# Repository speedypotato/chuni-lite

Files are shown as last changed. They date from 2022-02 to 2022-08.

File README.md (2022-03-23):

# chuni-lite
Slidy air towers for an arcade chuni slider without backplate.  Bare minimum docs because I don't expect too many people to have access to chuni cab sliders without backplates.

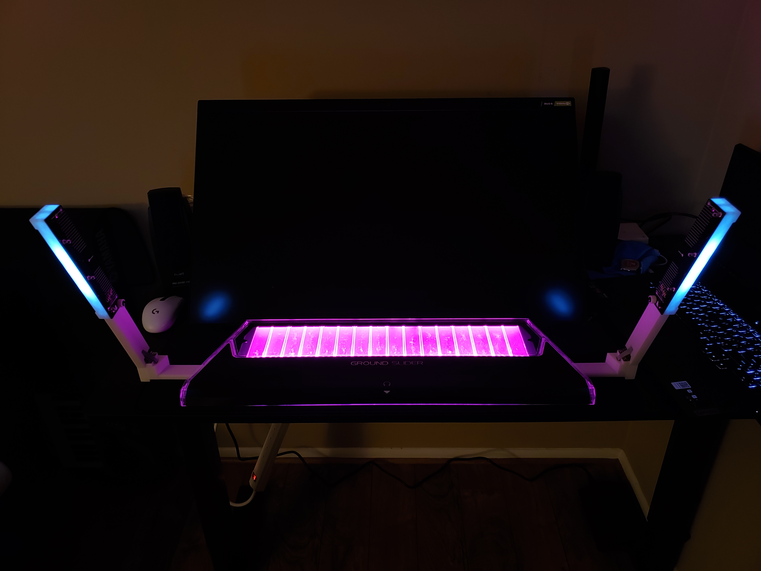
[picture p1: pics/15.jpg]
chuni lite


Current versions can be found at:
- CAD: chuni-lite\chunair-cad\airs\print\f1
- PCB: chuni-lite\chunair\chunair\chunair_v2\v2-1-2 & chuni-lite\chunair\chunair_core\v1

Note: I swapped the side the pads are on for chunair_core.  Oops.  Wires will go across the board for now, no biggie.  WS2811/WS2812B optional.

Slider needs:
- HiLetgo 2pcs DB9 Female Adapter RS232 to Terminal RS232 Serial to Terminal DB9 Connector Convert Adapter https://www.amazon.com/gp/product/B082F873KQ (technically just one)
- CQRobot 450 Pieces 2.54mm JST-XA JST Connector Kit. 2.54mm Pitch Female Pin Header, JST XA 2/3 / 4 Pin Housing JST Adapter Cable Connector Socket Male and Female, Crimp DIP Kit. https://www.amazon.com/gp/product/B085QMRHK6 (technically just a 3 & 4 pin).  3 pin needed pegs clipped.
- USB to VGA/RS-232 Male 9 PIN DB9 Serial Cable 2 FT WIN10/8.1/8/7 PERFECT VISION https://www.amazon.com/gp/product/B097Q5D64Q/ (or any other usb to serial cable)
- 12V 1A PSU minimum with matching female barrel jack that has the screw terminals https://www.amazon.com/gp/product/B091XSVV1Y/

Air towers need:
- 1x USB C Pro Micro x1
- IR LEDs https://www.amazon.com/gp/product/B01BVGIZGC/ and IR Photodiodes https://www.amazon.com/gp/product/B01BVGIZGM (chanzon ones seem pretty high quality) x6 of each(but they come in pack of 100)
- 150 ohm resistor x6
- 10k ohm resistor x6
- some ribbon wire https://www.ebay.com/itm/334199317464 100-Feet Flat Ribbon Cable Grey 50-Conductor 28 AWG Belden 2L28050 008H100
- 12x2mm magnets https://www.ebay.com/itm/391899288494 x10 (but they come in pack of 100)
- Rubber Feet https://www.mcmaster.com/8884T21 x4
- Adhesive Rubber Feet https://www.aliexpress.com/item/1005002618606773.html x4 (but they come in pack of 100)
- M3 Nuts x18
- M3x8 x4
- M4x16 https://www.mcmaster.com/91292A118 x4 (but they come in pack of 100)
- M3x15 flat head https://www.mcmaster.com/92125A103 x8 (but they come in pack of 100)
- M3x20 round head https://www.mcmaster.com/94500A266 x6 (but they come in pack of 100)
- 1 inch hinges https://www.amazon.com/gp/product/B07WJSTNC9 (MroMax 15PCS Door Hinge 1.14" x 0.71" x 0.02" Silver Tone Metal Iron Hinges Brushed Finish Suitable for Door Cabinet Jewelry Case Wooden Box) x2 (but pack of 15) - can try other hinges but holes may not align
- 3D printed parts + a mirrored set
- USB C cable
- Hot Glue & Super Glue
- Small zip ties x4

Can hand wire, or replace air_tower_top_1 3D print with chunair pcb.  chunair_core PCB also optional, but is there for ease of wiring(find a way to secure the pro micro if you don't use chunair_core)

Basic steps:
0. Wire up your slider's 12v and DB9.  Crimps recommended.  11" 4 wire recommended for 12v, 9" 3 wire for DB9.

xa 1

xa 2

xa 3

db9 and 12v

1. Print parts.  Then print a mirrored set.  Glue magnets with super glue except for the one on slider which is inserted from the outside - glue that one in with hot glue.  Pay attention to the magnetic poles!!

chunair 3d print

2. Assemble slider_rail and air_tower with hinge, flat head screws, and nuts and insert into slider (double check orientation)

hinge

3. Glue leds/pds if you are using air_tower_top_1.  Wire according to the diagram in "ac chuni/wiring.png".  If you have PCB, solder resistors and leds/pds - 10K resistors are marked, the other 3 are 150 ohm resistors.  With PCB, recommended wire length is around 30", 9 wires for RGB, 8 for no RGB.  
3a. If you want RGB, add a 3 piece WS2812B LED strip in the middle and solder it up like the picture.

led

led pcb

4. Shove unsoldered end of ribbon cable through the channel.
5. Screw air_tower_top_2 to the pcb or air_tower_top_1(depending on which you have) using rounded m3 heads while threading through air_tower.  Don't forget to put the printed bumper piece on one of the screws.

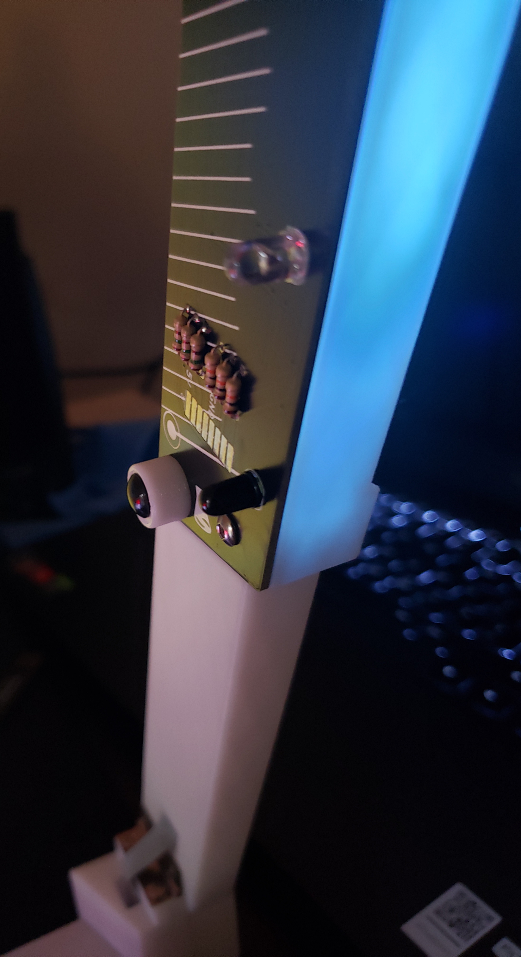
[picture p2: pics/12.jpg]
bumper


6. Solder to Pro Micro or chunair_core pcb depending on what you have.  Make sure you slide the slider_rail into the slider first before soldering.

chunair core

7. Repeat steps 2-6 for the other side.

chunair loose

chunair assembled

8. Add zip ties to core.  Use 4 m3x8 bolts and nuts to mount db9 and chunair_core to core.  Press fit 12v barrel connector and hot glue into place.

chunair core

9. Thread M4 screws through rubber foot and slider to mount to slider.

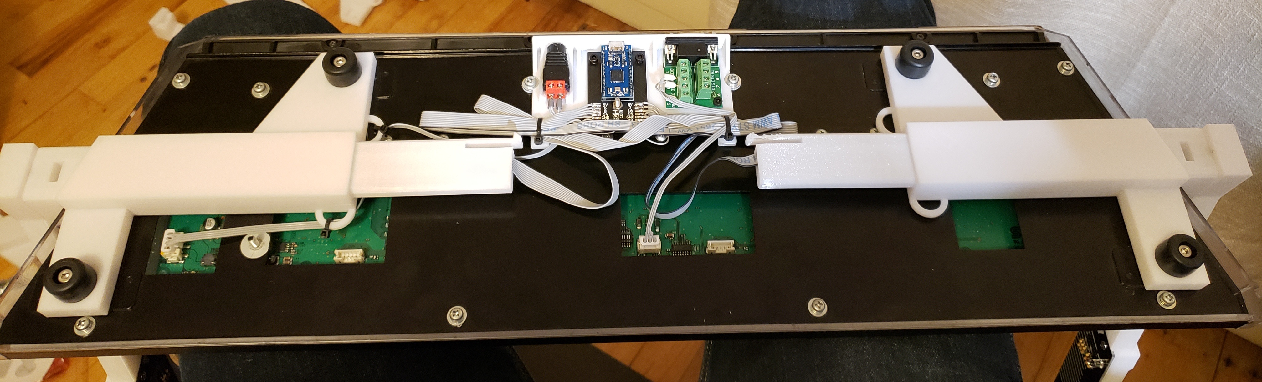
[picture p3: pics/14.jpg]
chunair core


10. Use existing M4 screws on the chunithm slider to mount core.  Zip tie down core & power cable
11. Flash firmware and test to make sure everything works.  Then add adhesive rubber feet on each bumper in addition to the bottom of the airs.

This work is licensed under a Creative Commons Attribution-NonCommercial-ShareAlike 4.0 International License.

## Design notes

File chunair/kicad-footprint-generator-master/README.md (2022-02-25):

This repository contains scripts to generate custom KiCAD footprints using python, and a framework which allows us to
create custom KiCAD footprint. A big bunch of footprints of the KiCad library was developed using this framework.

# KicadModTree

**Licence:** GNU GPLv3+

**Maintainer:** Thomas Pointhuber





**Supports:** Python 3.6+

## About

I started drawing a bunch of similar footprints for KiCAD, like connectors which are mainly one base shape, and different
amount of pins. To be able to update/improve those footprints quickly I decided to write my own footprint generator Framework,
to allow simple creation of easy as well complex shapes.

This is my second approach (the first one can be found in the git history). This solution should be able to be easy to
use, to read and also be easy to expand with custom nodes.

## Overview

This framework is mainly based on the idea of scripted CAD systems (for example OpenSCAD). This means, everything is a
node, and can be structured like a tree. In other words, you can group parts of the footprint, and translate them in any
way you want. Also cloning & co. is no problem anymore because of this concept.

To be able to create custom Nodes, I separated the system in two parts. Base nodes, which represents simple structures
and also be used by KiCAD itself, and specialized nodes which alter the behaviour of base nodes (for example positioning),
or represent a specialized usage of base nodes (for example RectLine).

When you serialize your footprint, the serialize command only has to handle base nodes, because all other nodes are based
upon the base nodes. This allows us to write specialized nodes without worrying about the FileHandlers or other core systems.
You simply create your special node, and the framework knows how to handle it seamlessly.

Please look into the **[Documentation](http://kicad-footprint-generator.readthedocs.io/en/latest/)** for further details

```
KicadModTree        - The KicadModTree framework which is used for footprint generation
docs                - Files required to generate a sphinx documentation
scripts             - scripts which are generating footprints based on this library
```

## Development

### Install development Dependencies

```sh
manage.sh update_dev_packages
```

### run tests

```sh
manage.sh tests
```

## Example Script

```python
from KicadModTree import *

footprint_name = "example_footprint"

# init kicad footprint
kicad_mod = Footprint(footprint_name)
kicad_mod.setDescription("A example footprint")
kicad_mod.setTags("example")

# set general values
kicad_mod.append(Text(type='reference', text='REF**', at=[0, -3], layer='F.SilkS'))
kicad_mod.append(Text(type='value', text=footprint_name, at=[1.5, 3], layer='F.Fab'))

# create silkscreen
kicad_mod.append(RectLine(start=[-2, -2], end=[5, 2], layer='F.SilkS'))

# create courtyard
kicad_mod.append(RectLine(start=[-2.25, -2.25], end=[5.25, 2.25], layer='F.CrtYd'))

# create pads
kicad_mod.append(Pad(number=1, type=Pad.TYPE_THT, shape=Pad.SHAPE_RECT,
                     at=[0, 0], size=[2, 2], drill=1.2, layers=Pad.LAYERS_THT))
kicad_mod.append(Pad(number=2, type=Pad.TYPE_THT, shape=Pad.SHAPE_CIRCLE,
                     at=[3, 0], size=[2, 2], drill=1.2, layers=Pad.LAYERS_THT))

# add model
kicad_mod.append(Model(filename="example.3dshapes/example_footprint.wrl",
                       at=[0, 0, 0], scale=[1, 1, 1], rotate=[0, 0, 0]))

# output kicad model
file_handler = KicadFileHandler(kicad_mod)
file_handler.writeFile('example_footprint.kicad_mod')
```
## Usage Steps

1. Navigate into the `scripts` directory, and look for the type of footprint you would like to generate. For example, if you wish to generate an SMD inductor footprint, `cd` into `scripts/Inductor_SMD`.
2. Open the \*.yaml (or \*.yml) file in a text editor. Study a few of the existing footprint definitions to get an idea of how your new footprint entry should be structured.
3. Add your new footprint by inserting your own new section in the file. An easy way to do this is by simply copying an existing footprint definition, and modifying it to suit your part. Note:  You may have to add or remove additional parameters that are not listed.
4. Save your edits and close the text editor.
5. Run the python script, passing the \*.yaml or (\*.yml) file as a parameter, e.g. `python3 Inductor_SMD.py Inductor_SMD.yml`. This will generate the \*.kicad_mod files for each footprint defined in the \*.yaml (or \*.yml).

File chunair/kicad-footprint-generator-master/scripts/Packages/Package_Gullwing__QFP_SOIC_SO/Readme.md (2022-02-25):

# IPC gullwing generator

This generator uses IPC-7351B equations and fillet definitions to derive a footprint for gullwing style packages from the dimensions of the package. (The suggested footprint is generally ignored. It is only used to define the exposed pad if necessary to fulfill thermal or EMC requirements defined in the datasheet.)
Fillet size definitions can be changed by pointing to a personalized IPC parameter file. The script generates footprints in zero orientation version A (pin 1 at top left corner).
Pads are generated using rounded rectangle pads as suggested in preliminary releases of IPC-7351C.

Examples of supported packages include: QFP, SOIC, SO.

## Running the script

The script requires python 3.4 or newer. Run it with:
`python3 ipc_gullwing_generator.py size_definitions/eqfp.yaml` (replace `eqfp.yaml` with the size definition file that contains your part.)

### Optional script parameters

* --global_config: the config file defining how the footprint will look like. (KLC) (default=`../../tools/global_config_files/config_KLCv3.0.yaml`)
* --series_config: the config file defining series parameters (footprint naming). (default=`../package_config_KLCv3.yaml`)

* --density: IPC density level (L,N,M) (default=`N`)
* --ipc_doc: IPC definition document (default=`../ipc_definitions.yaml`)

* --force_rectangle_pads: Force the generation of rectangle pads instead of rounded rectangle
* --kicad4_compatible: Create footprints compatible with version 4 (avoids round-rect and custom pads).

## Size definition format

Every file contains a header with parameters applied to all parts. These define the common footprint name prefix and the output library.

``` yaml
FileHeader:
  library_Suffix: 'QFP' #resulting library name Package_QFP
  device_type: 'EQFP' #footprint names will be of style ...EQFP-pincount_...
```

Alternatively, full output library name can be specified as following.

``` yaml
FileHeader:
  override_lib_name: 'Transformer_SMD' #resulting library name Transformer_SMD
  device_type: 'EQFP' #footprint names will be of style ...EQFP-pincount_...
```

---

Every further entry in the script is assumed to be a package size definition. The top level parameter will give the internal parameter set name. It must be unique in this file and should be representative of the footprint as it will be used in error messages. (It also makes later maintenance easier if it is easy to determine which footprint was generated by which parameter set.)

``` yaml
internal_package_name:
  # parameter list (See below)
```

### Documentation and naming parameters
- Size source to be added to footprint documentation field (`size_source`) {url}
- Footprint name generation control
  - Manufacturer name. Will be added as a prefix if given. (`manufacturer`) {string}
  - Part number. Will be added as a prefix if given. (`part_number`) {string}
  - Suffix: A custom suffix (added after pin pitch in default naming format). Can include parameters `pad_x` and `pad_y`.
  - Custom naming (`custom_name_format`) {python format string}
    - The full default format string is `{man:s}_{mpn:s}_{pkg:s}-{pincount:d}-1EP_{size_x:g}x{size_y:g}mm_P{pitch:g}mm{suffix:s}_EP{ep_size_x:g}x{ep_size_y:g}mm_Mask{mask_size_x:g}x{mask_size_y:g}mm{suffix2:s}{vias:s}` (The same parameters can be used in your custom format. Exposed pad parameters are not available for components without exposed pad.)

_Note: Contributions intended for the official library shall not include the manufacturer or part number unless the footprint is specific to that manufacturer or part. Similarly avoid custom naming for official library contributions unless required to achieve the requested name (Example TI-specific naming)._

### Package dimensions
dimension example
- Body size (`body_size_x`, `body_size_y`, `overall_height`) {dimension}
- Lead dimensions:
  - Overall size representing lead tip to lead tip dimension (`overall_size_x`, `overall_size_y`) {dimension}
  - Lead width (`lead_width`) {dimension}
  - Lead length distance between the lead bend and lead tip (`lead_len`) {dimension}
- Lead pitch, currently equal for all sides (`pitch`) {float}

### Pad count
- Pad count (`num_pins_x`, `num_pins_y`) {int}
  - `num_pins_x`=0 is used for generating SOIC-like packages.
  - `num_pins_y`=0 is used to generate SOIC-like package footprints but with inverted pin numbering. (Mirrored numbering scheme. Some manufactures use this style in their datasheets. Make sure you are not looking at the bottom view before using this. Not supported for QFP and similar.)
- Exclude pads by pad number (`exclude_pin_list`) {[`pad number`]}

### Exposed pad handling:
exposed pad example
- Size of package exposed pad or slug (`EP_size_x`, `EP_size_y`) {dimension}
- Size of the footprint pad [optional] (`EP_size_x_overwrite`, `EP_size_y_overwrite`) {float}
   - Pad size is equal to nominal package pad size if not given.
   - Use this to create a soldermask-defined pad.
- Optional the size of the mask cutout (`EP_mask_x`, `EP_mask_y`) {float}
   - Use to create soldermask-defined pads (in combination with `EP_size_x_overwrite`)
- Paste is split into a regular grid with (`EP_num_paste_pads`) {[int (x), int (y)]}
  - The optional paste coverage multiplier determines how much of the exposed copper area is covered by paste. (`EP_paste_coverage`) {float (0..1), default=0.65}

### Rounding of exposed pad features
IPC excludes exposed pads from the requirement for rounding its corners. By default the exposed pad does therefore not use rounded corners. Some datasheets do however suggest the use of rounded corners either specified to a specific value or they appear to be equal to the normal pads.

rounded exposed pad example

- Paste corner rounding is controlled by global config parameters `paste_radius_ratio` and
`paste_maximum_radius` {float}
- The round radius of the exposed pad can be directly set with `EP_round_radius` {float/"pad"}
  - The string "pad" can be used to force the same radius for the exposed pad as for the normal pads.
  - Alternatively the round radius ratio and max radius can be set using (`EP_round_radius_ratio`, `EP_maximum_radius`) {float}
    - Both these can be set per-footprint or in the global config file.

### Thermal vias
A package with exposed pad can generate a version with thermal vias. This will be generated in addition to the normal version.

exposed pad example

``` yaml
  thermal_vias:
    # thermal via version parameters
```
- Number of vias generated in the regular grid (`count`) {[int (x), int (y)]}
- Final hole size (`drill`) {float}
- Optional grid (`grid`) {[float (x), float (y)]}
  - Auto-generated if not given (outermost pad will touch pad edge).
- Paste coverage overwrite [optional] (`EP_paste_coverage`) {float (0..1)}
  - Thermal via version might need higher paste coverage compared to non-via version to compensate solder lost due to wicking.
- Paste generator can be set up to avoid placing paste on top of vias (`paste_avoid_via`) {bool}
  - Clearance between via hole and paste (`paste_via_clearance`) {float}
  - Can lead to math exceptions. Possible fixes:
     - Reduce paste coverage (make sure you still have enough paste)
     - Play with the via grid and number of paste pads (having an outer ring of paste pads often helps. This is only possible if there is space on the outside)
     - If no fix is satisfactory then select avoid vias as false and increase paste coverage to combat solder loss.
- Number paste pads
  - Quantity of paste pads (`EP_num_paste_pads`) {[int (x), int (y)]}
  - Alternative available if `paste_avoid_via` is true
    - Number of paste pads between 4 vias (`paste_between_vias`) {[int (x), int (y)]}
    - Number of additional paste pad rings outside the outermost vias [optional] (`paste_rings_outside`) {[int (x), int (y)]}

## Dimension parameter format
Dimensions in datasheets are either given with minimum and maximum value (optionally including nominal) or with the nominal value plus a tolerance. Some values of the datasheet are given as reference value without tolerance. (Tolerances in this measurement are already included in other dimensions.) The script reflects this by offering the same options.

Always include the nominal dimension if the tolerance is asymmetrical as the resulting footprint will differ if it is not included.

_Note: Contributions that are intended for the official KiCad library must use the same dimensioning format as the datasheet. (If min, nom and max are given then all 3 must be entered into the YAML file even if the tolerance is symmetrical. Similarly use nominal plus tolerance format if the datasheet is dimensioned this way.)_

### String-based

The parameter can be given as a string in one of the following formats (white space characters are ignored).

```yaml
parameter_name: 1.2 # nominal only (reference dimension marked as such in datasheet)
parameter_name: 1.1 .. 1.2 .. 1.3 # min .. nominal .. max
parameter_name: 1.1 .. 1.3 # min .. max
parameter_name: 1.2 +/-0.1 # nominal plus symmetrical tolerance
parameter_name: 1.2 +0.1 -0.05 # nominal plus asymmetrical tolerance
```

### Dict-based

```yaml
parameter_name: # nominal only
  nominal: 1.2
  tolerance: 0 # optional to make it clear that this is the case
parameter_name: # minimum maximum and nominal
  minimum: 1.1
  nominal: 1.2
  maximum: 1.3
parameter_name: # minimum maximum
  minimum: 1.1
  maximum: 1.3
parameter_name: # nominal with symmetrical tolerance
  nominal: 1.2
  tolerance: 0.1
parameter_name: # nominal with asymmetrical tolerance
  nominal: 1.2
  tolerance: [-0.05, 0.1] # order does not matter, the sign is important.
```

### Deprecated format

Support for this format will be dropped in the future. This format only supports min, nom, max dimensioning.

```yaml
parameter_name_min: 1.1
parameter_name: 1.2
parameter_name_max: 1.3
```

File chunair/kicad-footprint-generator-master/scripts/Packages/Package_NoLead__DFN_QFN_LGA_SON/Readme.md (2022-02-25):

# IPC Footprint Generator for No Lead Packages

This generator uses IPC-7351B equations and fillet definitions to derive a footprint for no-lead style packages from the dimensions of the package. (The suggested footprint is generally ignored. It is only used to define the exposed pad if necessary to fulfill thermal or EMC requirements defined in the datasheet.)
Fillet size definitions can be changed by pointing to a personalized IPC parameter file. The script generates footprints in zero orientation version A (pin 1 at top left corner).
Pads are generated using rounded rectangle pads as suggested in preliminary releases of IPC-7351C.

Examples of supported packages include: DFN, QFN, SON, LGA.

## Running the Script

The script requires python 3.4 or newer. Run it with:
`python3 ipc_noLead_generator.py size_definitions/dfn.yaml` (replace `dfn.yaml` with the size definition file that contains your part.)

### Optional Script Parameters

* --global_config: the config file defining how the footprint will look like. (KLC) (default=`../../tools/global_config_files/config_KLCv3.0.yaml`)
* --series_config: the config file defining series parameters (footprint naming). (default=`../package_config_KLCv3.yaml`)

* --density: IPC density level (L,N,M) (default=`N`)
* --ipc_doc: IPC definition document (default=`../ipc_definitions.yaml`)

* --force_rectangle_pads: Force the generation of rectangle pads instead of rounded rectangle
* --kicad4_compatible: Create footprints compatible with version 4 (avoids round-rect and custom pads).

## Size Definition Format

The size definition file contains one entry per package size definition. The top level parameter will give the internal parameter set name. It must be unique in this file and should be representative of the footprint as it will be used in error messages. (It also makes later maintenance easier if it is easy to determine which footprint was generated by which parameter set.)

``` yaml
internal_package_name:
  # parameter list (See below)
```

### Documentation and Naming Parameters
- Size source to be added to footprint documentation field (`size_source`) {url}
- Footprint library name (`library`) {string}
- Footprint name generation control
  - Device type added as prefix. Example QFN. (`device_type`) {string}
  - Selection of an alternative name format. Example for LGA footprints. (`use_name_format`) {enum(`LGA`, `not LGA`)}
  - Manufacturer name. Will be added as a prefix if given. (`manufacturer`) {string}
  - Part number. Will be added as a prefix if given. (`part_number`) {string}
  - Suffix: A custom suffix (added after pin pitch in default naming format). Can include parameters `pad_x` and `pad_y`.
  - Custom naming (`custom_name_format`) {python format string}
    - The full default format string is `{man:s}_{mpn:s}_{pkg:s}-{pincount:d}-1EP_{size_x:g}x{size_y:g}mm_P{pitch:g}mm{suffix:s}_EP{ep_size_x:g}x{ep_size_y:g}mm_Mask{mask_size_x:g}x{mask_size_y:g}mm{suffix2:s}{vias:s}` (The same parameters can be used in your custom format. Exposed pad parameters are not available for components without exposed pad.)

_Note: Contributions intended for the official library shall not include the manufacturer or part number unless the footprint is specific to that manufacturer or part. Similarly avoid custom naming for official library contributions unless required to achieve the requested name (Example TI-specific naming)._

### Package Dimensions
dimension example
- Body size (`body_size_x`, `body_size_y`, `overall_height`) {dimension}
- Lead dimensions:
  - Lead width (`lead_width`) {dimension}
  - Lead length (`lead_len`) {dimension}
    - Optional for specifying different length for horizontal and vertical leads (`lead_len_H`, `lead_len_V`) {dimension}
- Lead pitch, currently equal for all sides (`pitch`) {float}

#### Pull Back Leads
By default the leads are assumed to extend to the body edge. On some packages the leads are inset within the package body and these are called "pull back" leads. A typical example are packages that are called LGA by manufacturers.
These packages need to select the pull back option for the IPC class (`ipc_class: 'qfn_pull_back'`) and need to be able to specify where the lead is.

dimension example for pull back leads

- Most manufacturers give the lead pull back distance (`lead_to_edge`) {dimension}
   - Alternatively the center position can be given (`lead_center_pos_x` and `lead_center_pos_y`) {dimension}
   - Another alternative is to give the center to center dimensions for leads. (`lead_center_to_center_x` and `lead_center_to_center_y`) {dimension}
- Some manufacturers give the body to inner edge dimension instead of the lead length (`body_to_inside_lead_edge`) {dimensions}

### Pad Count
- Pad count (`num_pins_x`, `num_pins_y`) {int}
  - `num_pins_x`=0 is used for generating DFN-like packages.
  - `num_pins_y`=0 is used to generate DFN-like package footprints but with inverted pin numbering. (Mirrored numbering scheme. Some manufactures use this style in their datasheets. Make sure you are not looking at the bottom view before using this. Not supported for QFN and similar.)

### Exposed pad Handling:
exposed pad example
- Size of package exposed pad or slug (`EP_size_x`, `EP_size_y`) {dimension}
- Size of the footprint pad [optional] (`EP_size_x_overwrite`, `EP_size_y_overwrite`) {float}
   - Pad size is equal to nominal package pad size if not given.
   - Use this to create a soldermask-defined pad.
- Optional the size of the mask cutout (`EP_mask_x`, `EP_mask_y`) {float}
   - Use to create soldermask-defined pads (in combination with `EP_size_x_overwrite`)
- Paste is split into a regular grid with (`EP_num_paste_pads`) {[int (x), int (y)]}
  - The optional paste coverage multiplier determines how much of the exposed copper area is covered by paste. (`EP_paste_coverage`) {float (0..1), default=0.65}

### Rounding of Exposed Pad Corners
IPC excludes exposed pads from the requirement for rounding its corners. By default the exposed pad does therefore not use rounded corners. Some datasheets do however suggest the use of rounded corners either specified to a specific value or they appear to be equal to the normal pads.

rounded exposed pad example

- Paste corner rounding is controlled by global config parameters `paste_radius_ratio` and
`paste_maximum_radius` {float}
- The round radius of the exposed pad can be directly set with `EP_round_radius` {float/"pad"}
  - The string "pad" can be used to force the same radius for the exposed pad as for the normal pads.
  - Alternatively the round radius ratio and max radius can be set using (`EP_round_radius_ratio`, `EP_maximum_radius`) {float}
    - Both these can be set per-footprint or in the global config file.

### Thermal Vias
A package with exposed pad can generate a version with thermal vias. This will be generated in addition to the normal version.

exposed pad example

``` yaml
  thermal_vias:
    # thermal via version parameters
```
- Number of vias generated in the regular grid (`count`) {[int (x), int (y)]}
- Final hole size (`drill`) {float}
- Optional grid (`grid`) {[float (x), float (y)]}
  - Auto-generated if not given (outermost pad will touch pad edge).
- Paste coverage overwrite [optional] (`EP_paste_coverage`) {float (0..1)}
  - Thermal via version might need higher paste coverage compared to non-via version to compensate solder lost due to wicking.
- Paste generator can be set up to avoid placing paste on top of vias (`paste_avoid_via`) {bool}
  - Clearance between via hole and paste (`paste_via_clearance`) {float}
  - Can lead to math exceptions. Possible fixes:
     - Reduce paste coverage (make sure you still have enough paste)
     - Play with the via grid and number of paste pads (having an outer ring of paste pads often helps. This is only possible if there is space on the outside)
     - If no fix is satisfactory then select avoid vias as false and increase paste coverage to combat solder loss.
- Number paste pads
  - Quantity of paste pads (`EP_num_paste_pads`) {[int (x), int (y)]}
  - Alternative available if `paste_avoid_via` is true
    - Number of paste pads between 4 vias (`paste_between_vias`) {[int (x), int (y)]}
    - Number of additional paste pad rings outside the outermost vias [optional] (`paste_rings_outside`) {[int (x), int (y)]}

## Dimension Parameter Format
Dimensions in datasheets are either given with minimum and maximum value (optionally including nominal) or with the nominal value plus a tolerance. Some values of the datasheet are given as reference value without tolerance. (Tolerances in this measurement are already included in other dimensions.) The script reflects this by offering the same options.

Always include the nominal dimension if the tolerance is asymmetrical as the resulting footprint will differ if it is not included.

_Note: Contributions that are intended for the official KiCad library must use the same dimensioning format as the datasheet. (If min, nom and max are given then all 3 must be entered into the YAML file even if the tolerance is symmetrical. Similarly use nominal plus tolerance format if the datasheet is dimensioned this way.)_

### String-based

The parameter can be given as a string in one of the following formats (white space characters are ignored).

```yaml
parameter_name: 1.2 # nominal only (reference dimension marked as such in datasheet)
parameter_name: 1.1 .. 1.2 .. 1.3 # min .. nominal .. max
parameter_name: 1.1 .. 1.3 # min .. max
parameter_name: 1.2 +/-0.1 # nominal plus symmetrical tolerance
parameter_name: 1.2 +0.1 -0.05 # nominal plus asymmetrical tolerance
```

### Dict-based

```yaml
parameter_name: # nominal only
  nominal: 1.2
  tolerance: 0 # optional to make it clear that this is the case
parameter_name: # minimum maximum and nominal
  minimum: 1.1
  nominal: 1.2
  maximum: 1.3
parameter_name: # minimum maximum
  minimum: 1.1
  maximum: 1.3
parameter_name: # nominal with symmetrical tolerance
  nominal: 1.2
  tolerance: 0.1
parameter_name: # nominal with asymmetrical tolerance
  nominal: 1.2
  tolerance: [-0.05, 0.1] # order does not matter, the sign is important.
```

### Deprecated format

Support for this format will be dropped in the future. This format only supports min, nom, max dimensioning.

```yaml
parameter_name_min: 1.1
parameter_name: 1.2
parameter_name_max: 1.3
```

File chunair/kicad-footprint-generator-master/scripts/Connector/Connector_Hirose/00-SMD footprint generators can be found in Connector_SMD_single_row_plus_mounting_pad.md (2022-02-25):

The following connector footprints are generated in the generic script located in ../Connector_SMD_single_row_plus_mounting_pad/

- DF52

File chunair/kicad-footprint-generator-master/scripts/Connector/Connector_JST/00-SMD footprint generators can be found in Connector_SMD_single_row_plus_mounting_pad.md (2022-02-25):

The following connector footprints are generated in the generic script located in ../Connector_SMD_single_row_plus_mounting_pad/

- 'ACH'
- 'AUH'
- 'LEA'
- 'GH'
- 'PH' (only SMD version = `*PH-SM4*`)
- 'SFH'
- 'SHL'
- 'SH'
- 'SUR'
- 'XAG'
- 'ZE'

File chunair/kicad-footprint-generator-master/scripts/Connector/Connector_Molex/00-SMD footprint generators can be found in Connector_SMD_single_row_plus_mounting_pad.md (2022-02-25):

The following connector footprints are generated in the generic script located in ../Connector_SMD_single_row_plus_mounting_pad/

- 'Panelmate'
  - '53780-{pincount:02d}70'
- 'Pico-EZmate'
  - '78171-00{pincount:02d}'
- 'Pico-EZmate_Slim'
  - '202656-0{pincount:02d}1'
- 'PicoBlade'
  - '53398-{pincount:02d}71'
- 'PicoBlade'
  - '53261-{pincount:02d}71'
- 'Pico-Clasp'
  - '501331-{pincount:02d}07'
- 'Pico-Clasp'
  - '501331-{pincount:02d}07'
- 'Pico-Clasp'
  - '202396-{pincount:02d}07'
- 'Pico-Lock'
  - '504050-{pincount:02d}91'

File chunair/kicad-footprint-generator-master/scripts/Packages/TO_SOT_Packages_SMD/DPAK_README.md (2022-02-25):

# DPAK footprint generator

Program to generate KiCad footprints using KicadModTree from https://github.com/pointhi/kicad-footprint-generator

Devices included:
- TO252 / DPAK
- TO263 / D2PAK / DDPAK
- TO268 / D3PAK
- ATPAK

## Usage

Download `kicad-footprint-generator` from https://github.com/pointhi/kicad-footprint-generator

Install the following files in the folder `.../kicad-footprint-generator/scripts/<category>/`.

```
DPAK.py
DPAK_config.yaml
make_DPAK.py
```

To generate the footprints, run one of the following commands:

```
$ python3 ./make_DPAK.py         # builds all device types
$ python3 ./make_DPAK.py <type>  # builds specified type only, where type is one of TO252, TO263, TO268 or ATPAK
```

## Configuration

The program `make_DPAK.py` uses classes in `DPAK.py` to build the models.  Design parameters for each device type and its variants (for example, number of pins, whether centre pin is cut) are contained in `DPAK_config.yaml`.

The configuration for each device type is a separate YAML document in the configuration file (separated by `---`).  The document for each type is broken into a `base:` section (values that apply to all devices in the family) and a `variants:` section with separate entries for each individual device.

*The configuration file is shared with the 3D model generator program.  Configuration items required for the 3D models are marked with `# 3D` in the descriptions below.*

### `base:` configuration

```
series: TO-252                   # 3D
```

The package name is included in the names of the module files generated by the program. It can also be passed as a command line argument to limit which devices are generated.

```
description: 'TO-252 / DPAK SMD package'
keywords: 'DPAK TO-252'
```

These strings are combined with the device-specific description and keywords (see below) and are included in the module file.

```
footprint:
    x_mm: 10.6
```

The next part of the configuration file is about the footprint (i.e. the land pattern of copper pads). `x_mm` is the overall size of the footprint: the X distance between the left hand edge of the pin pads and the right hand edge of the tab pads.

```
tab:
    x_mm: 6.4
    y_mm: 5.8
```

This defines the size of the tab pad.

```
split_paste: 'on'
paste_gutter_mm: 0.3
```

If `split_paste` is `on`, the paste mask for the tab will be divided into four parts with a gap (gutter) between them.

```
device:
    x_mm: 9.9                    # 3D
```

The next part of the configuration file is about the phyical device that sits on the footprint. `x_mm` is the overall size of the device: the X distance between the end of the pins and the right hand edge of the tab.

```
body:
    x_mm: 6.22                   # 3D
    y_mm: 6.5                    # 3D
    z_mm: 2.3                    # 3D
    waist_z_mm: 1.2              # 3D
    marker_offset_x_mm: -1.5     # 3D
    colour: 'black body'         # 3D
tab:
    x_mm: 1.0                    # 3D
    y_mm: 5.4                    # 3D
    z_mm: 1.0                    # 3D
    project_x_mm: 1.0            # 3D
    colour: 'metal grey pins'    # 3D
```

These define the size of the body and tab. Tab `x_mm` includes the part of the tab under the body. `project_x_mm` is the part of the tab that projects outside the body.

```
marker:
    x_mm: 1.5                    # 3D
    z_mm: 0.1                    # 3D
```

These define the diameter and depth of the marker on top of the body.

```
pins:
    colour: 'metal grey pins'    # 3D
```

Used for the 3D model. See below for configuration data for the pins on each variant.

```
3d_prefix: '${KICAD6_3DMODEL_DIR}/TO_SOT_Packages_SMD.3dshapes'
```

This string is added to the module to set the path to the 3D models folder.

### `variants:` configuration

The variants section contains a list of one or more device definitions.

```
- pins: 3                        # 3D
  pitch_mm: 2.28                 # 3D
```

The `-` character starts the device definition. The first two settings are the number of pins and the pitch (Y distance between them).

```
  pad:
      x_mm: 2.2
      y_mm: 1.2
  pin:
      x_mm: 2.7
      y_mm: 0.75                 # 3D
      z_mm: 0.5                  # 3D
      cut_x_mm: 0.8              # 3D
```

These define the size of the pads and pins.  The pin `x_mm` is the X distance from the end of an uncut pin to the device body, while `cut_x_mm` is the equivalent for a cut pin.

```
   centre_pin: ['cut', 'uncut']  # 3D
```

This parameter contains either one or both of `'cut'` or '`uncut`'. If both are present, the program will generate two modules, one with a pad for the centre pin and one without.  If just one is present, only one module will be generated.

```
  keywords: 'DPAK-3 TO-252-3 SOT-428'
  datasheet: http://www.infineon.com/cms/en/product/packages/PG-TO252/PG-TO252-3-1/
```

These strings are added to the base-level description and keywords (see above) and are included in the module.

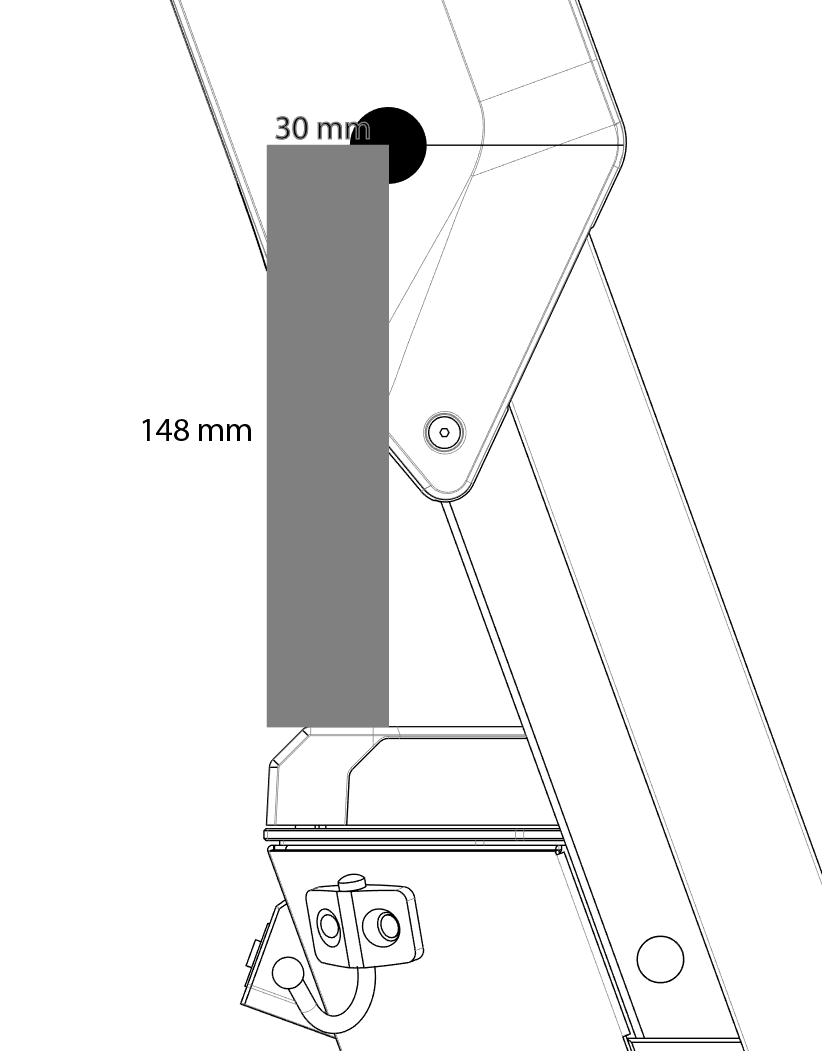
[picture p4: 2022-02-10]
chunair-cad/led_height.png

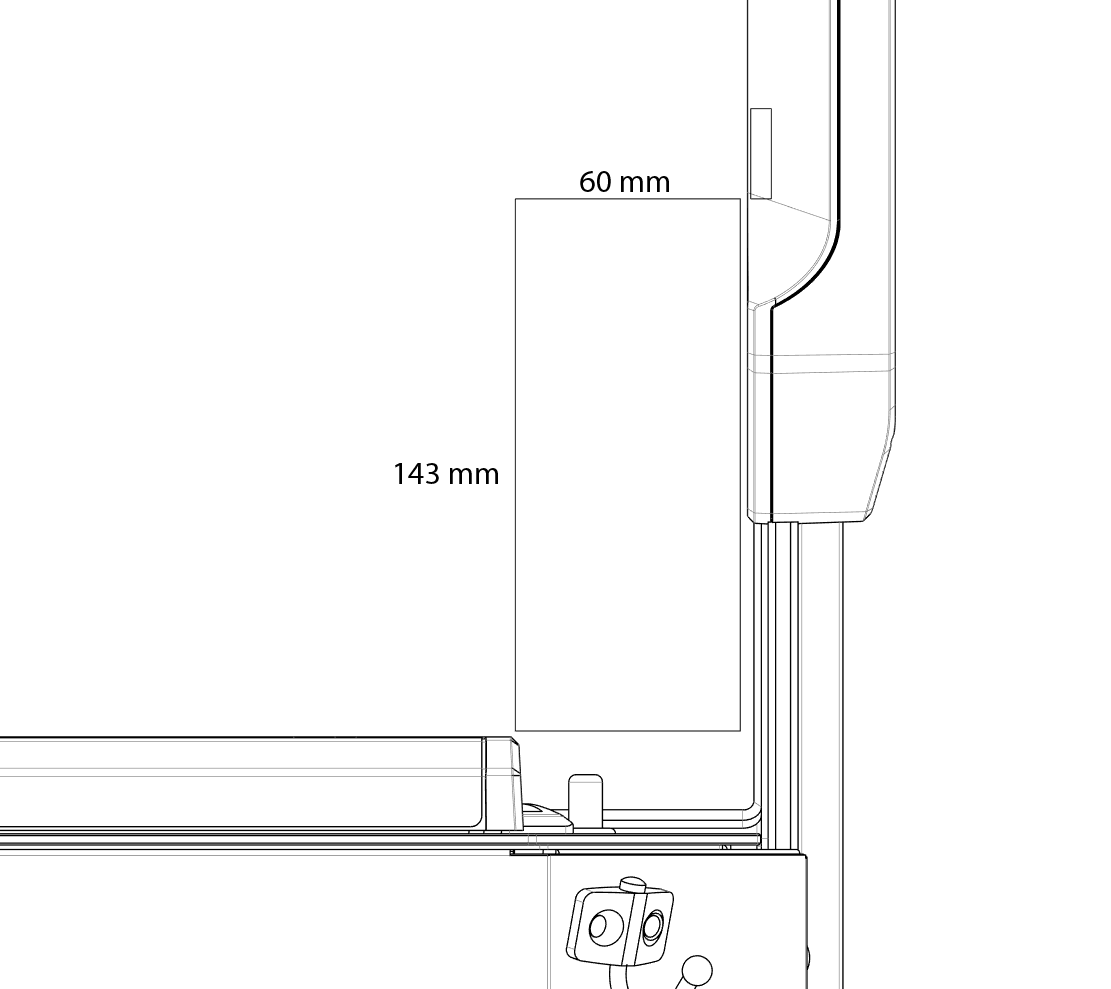
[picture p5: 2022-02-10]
chunair-cad/led_width.png

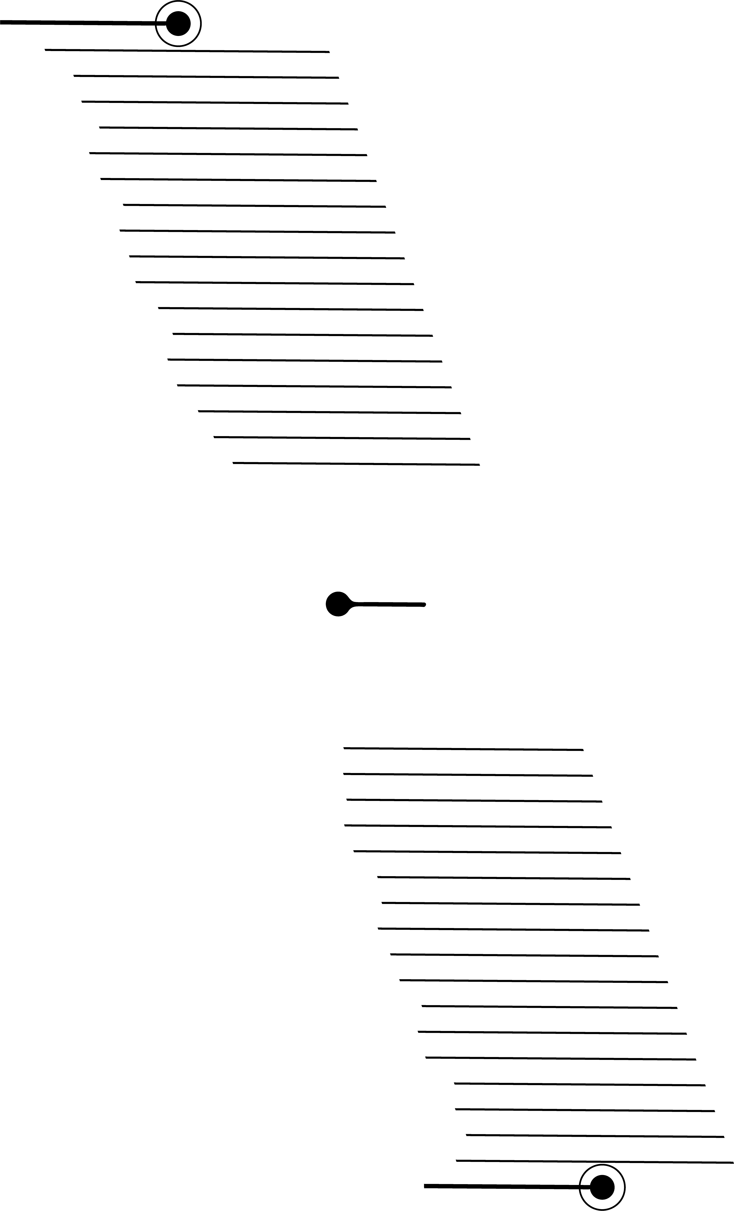
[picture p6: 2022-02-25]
chunair/air_graphics/air_tower_top_1_export.png

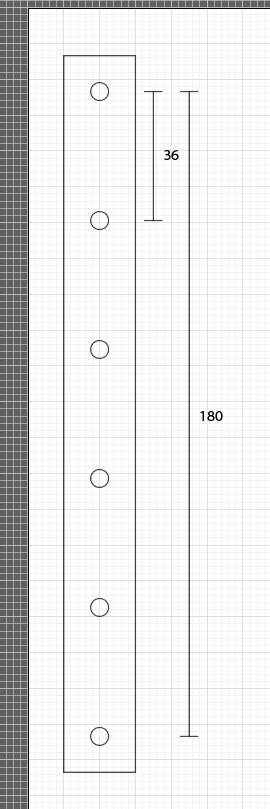
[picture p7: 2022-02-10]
chunair-cad/led_spacing.png

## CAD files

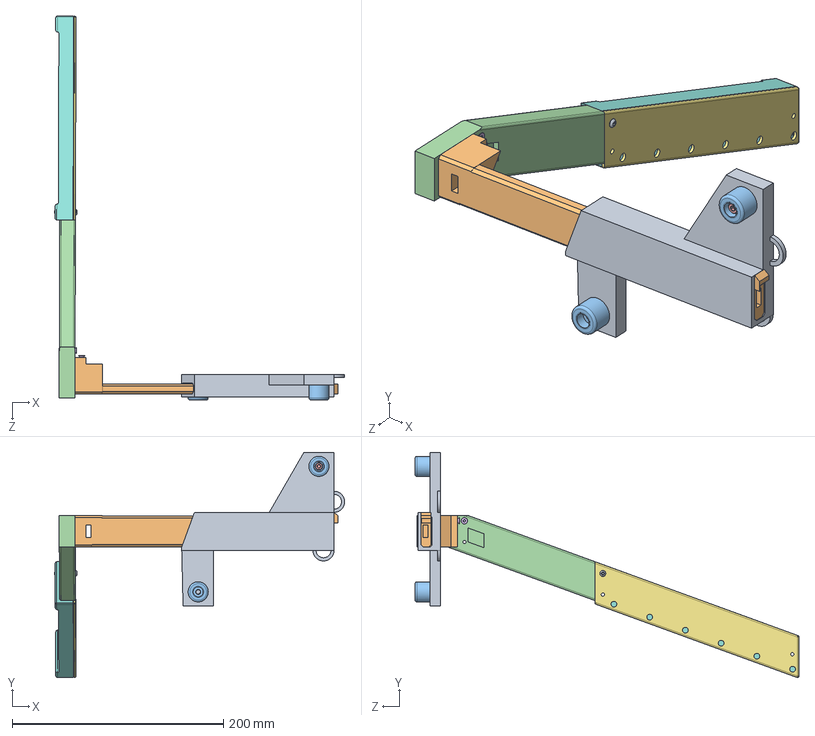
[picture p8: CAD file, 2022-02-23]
chunair-cad/airs/ac_chuni.SLDASM
274.8 x 213.0 x 363.5 mm
slider
slider_rail
8884T21_Heavy Duty Unthreaded Bumpers x 2
air_tower
91292A118_18-8 Stainless Steel Socket Head Screw
92125A103_18-8 Stainless Steel Hex Drive Flat Head Screw x 2
air_tower_top_1
air_tower_top_2
94500A266_316 Stainless Steel Button Head Hex Drive Screws

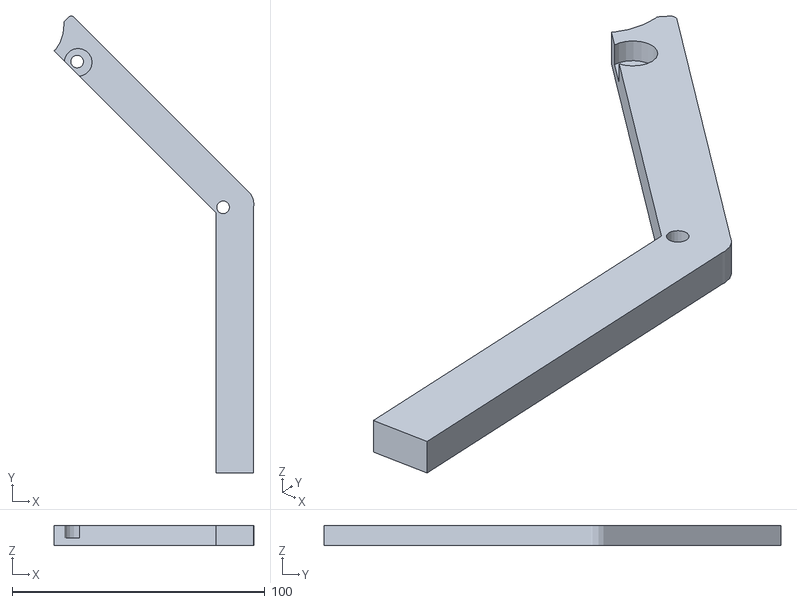
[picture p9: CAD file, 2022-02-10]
chunair-cad/air_spacer.stl
79.1 x 180.6 x 8.00

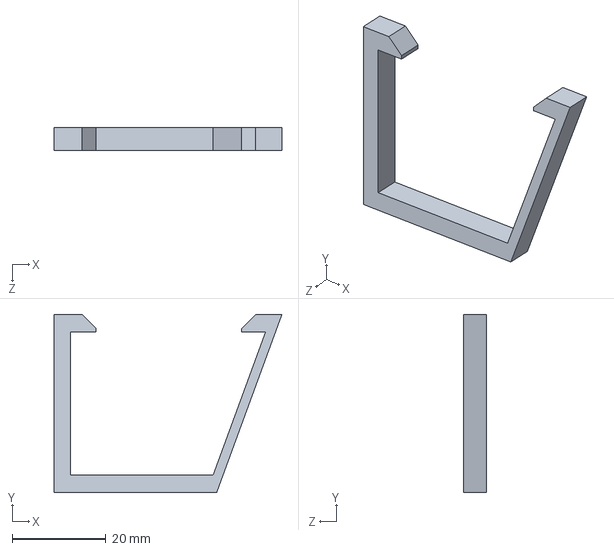
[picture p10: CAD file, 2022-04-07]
chunair-cad/airs/clip.SLDPRT
48.6 x 38.0 x 5.00 mm

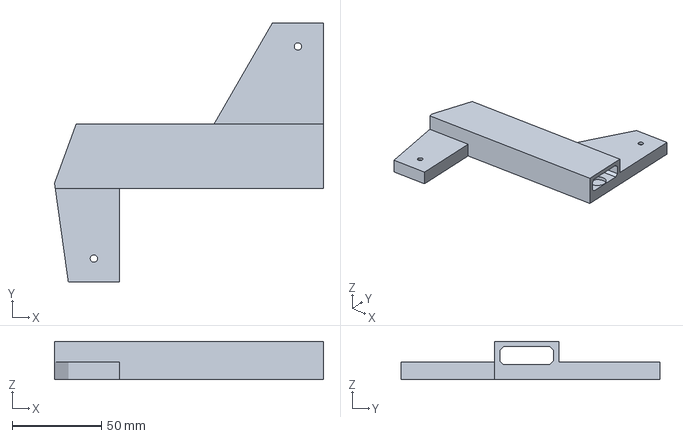
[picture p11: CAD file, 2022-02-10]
chunair-cad/airs/print/a1/slider.3MF
150.7 x 145.1 x 21.5 mm

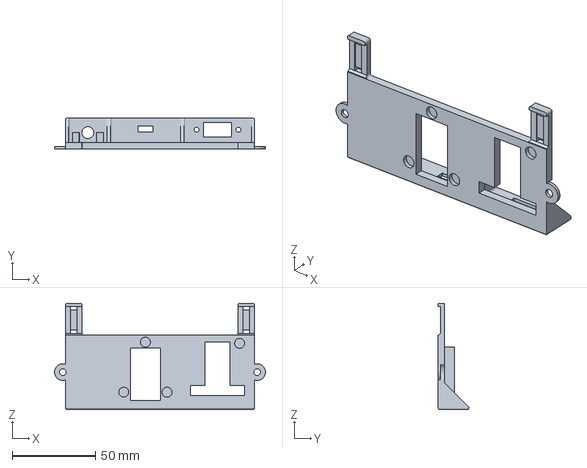
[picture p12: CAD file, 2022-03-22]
chunair-cad/airs/print/a10/core.3MF
126.5 x 18.5 x 63.8 mm

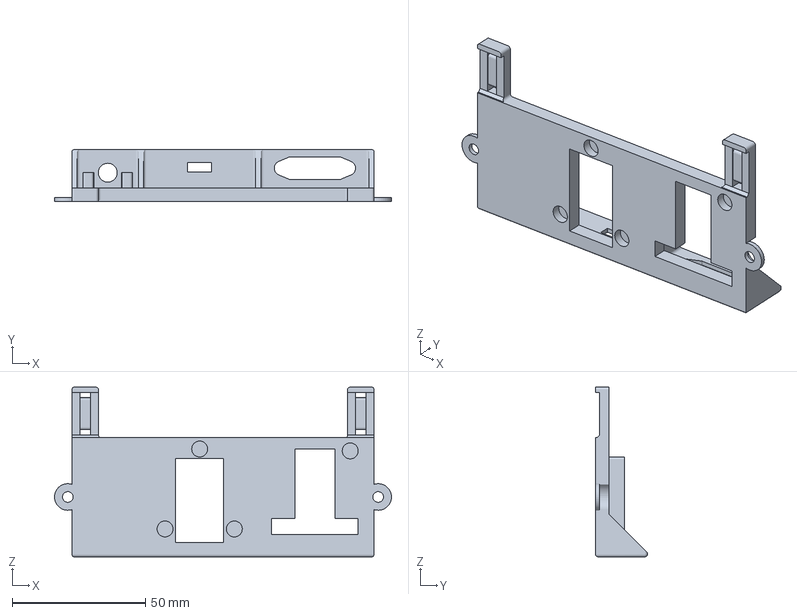
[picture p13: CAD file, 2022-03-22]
chunair-cad/airs/print/a11/core.3MF
126.5 x 19.5 x 63.8 mm

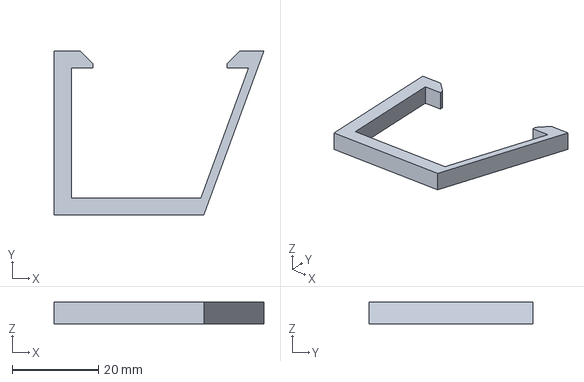
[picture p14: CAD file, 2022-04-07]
chunair-cad/airs/print/a12/clip.3MF
48.6 x 38.0 x 5.00 mm

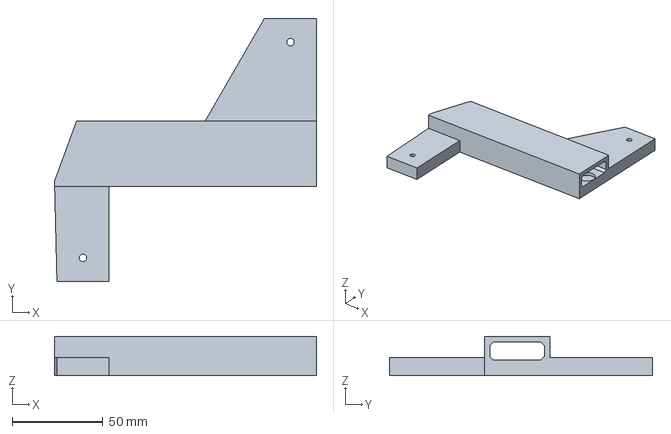
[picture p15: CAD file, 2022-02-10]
chunair-cad/airs/print/a2/slider.3MF
144.3 x 145.1 x 21.5 mm

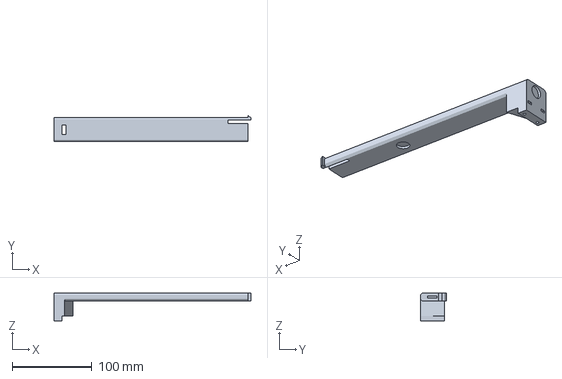
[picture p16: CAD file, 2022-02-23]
chunair-cad/airs/print/a3/slider_rail.3MF
247.0 x 33.0 x 34.5 mm

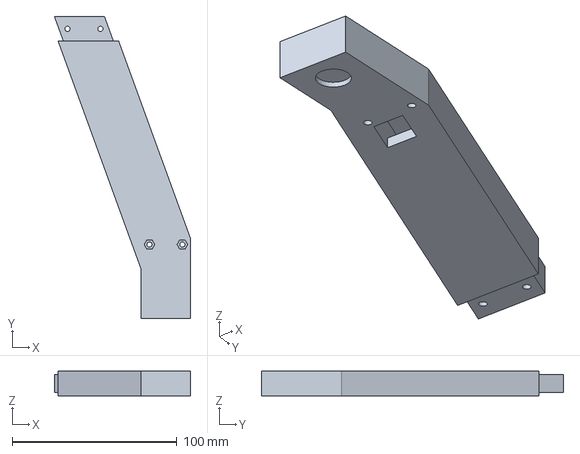
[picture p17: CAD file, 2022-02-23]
chunair-cad/airs/print/a5/air_tower.3MF
82.8 x 183.5 x 15.0 mm

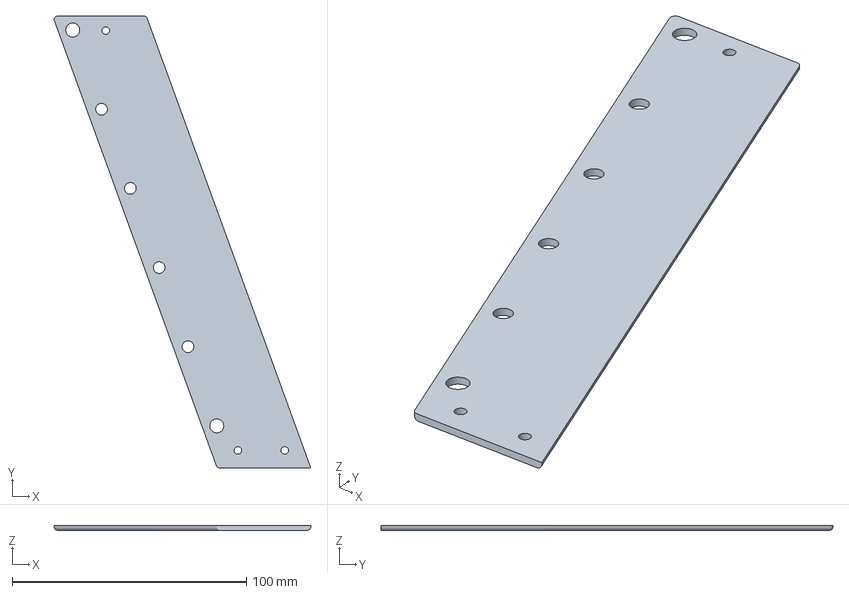
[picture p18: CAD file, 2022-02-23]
chunair-cad/airs/print/a6/air_tower_top_1.3MF
109.7 x 193.1 x 2.00 mm

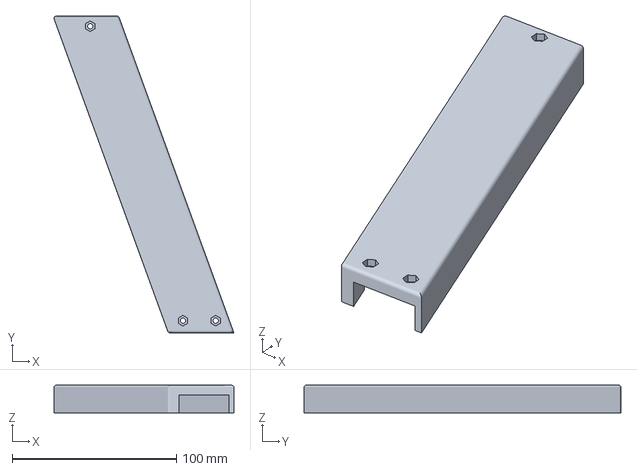
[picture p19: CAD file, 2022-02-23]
chunair-cad/airs/print/a7/air_tower_top_2.3MF
109.7 x 193.1 x 17.0 mm

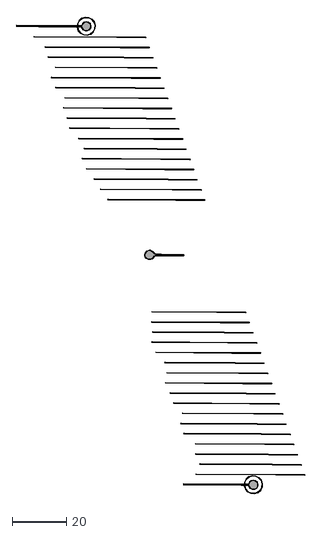
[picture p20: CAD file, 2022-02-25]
chunair/air_graphics/air_tower_top_1_export.dxf
106.4 x 176.5

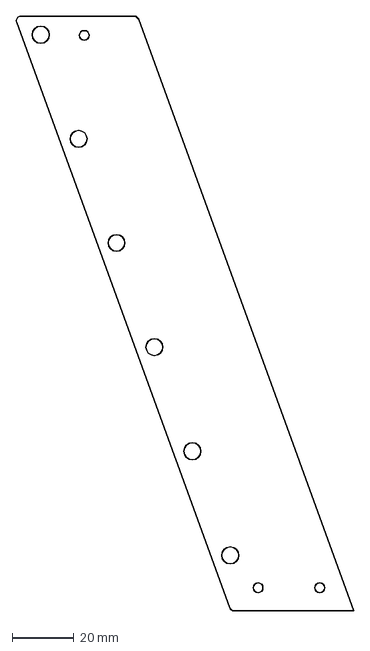
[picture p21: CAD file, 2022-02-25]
chunair/chunair/air_tower_top_1.DXF
109.8 x 193.1 mm

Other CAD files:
chunair-cad/airs/print/a4/slider_rail.3MF
chunair-cad/airs/print/a8/air_tower_top_2.3MF
chunair-cad/airs/print/a9/core.3MF
chunair-cad/airs/print/f1/clip.3MF
chunair-cad/airs/air_tower.SLDPRT
chunair-cad/airs/air_tower_top_1.SLDPRT
chunair-cad/airs/air_tower_top_2.SLDPRT
chunair-cad/airs/bumper.SLDPRT
chunair-cad/airs/core.SLDPRT
chunair-cad/airs/print/a12/bumper.3MF
chunair-cad/airs/print/a12/core.3MF
chunair-cad/airs/print/a3/air_tower.3MF
chunair-cad/airs/print/a3/slider.3MF
chunair-cad/airs/print/a5/slider_rail.3MF
chunair-cad/airs/print/a6/air_tower.3MF
chunair-cad/airs/print/a6/air_tower_top_2.3MF
chunair-cad/airs/print/a6/slider.3MF
chunair-cad/airs/print/a6/slider_rail.3MF
chunair-cad/airs/print/a7/air_tower_top_1.3MF
chunair-cad/airs/print/a8/slider.3MF
chunair-cad/airs/print/a8/slider_rail.3MF
chunair-cad/airs/print/a9/air_tower.3MF
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

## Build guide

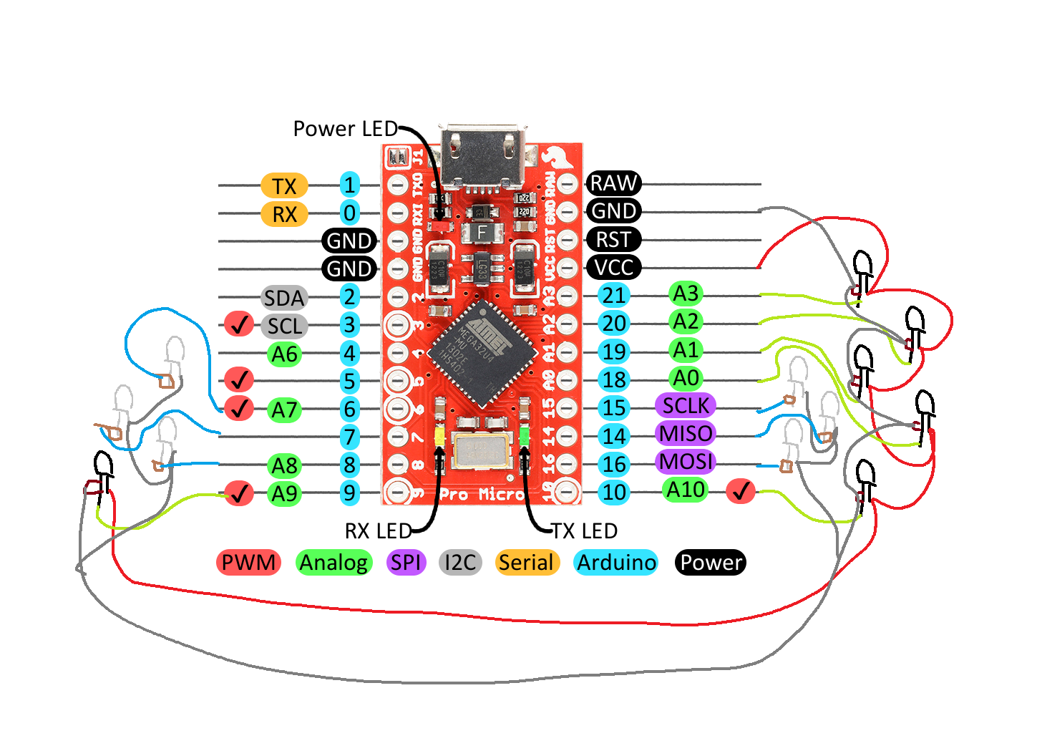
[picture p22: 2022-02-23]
chunair-cad/wiring.png

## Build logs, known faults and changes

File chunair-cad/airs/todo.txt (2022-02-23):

TODO
angle one side of hinge so screw heads don't collide?

DONE
need +3/4mm on bottom of air tower to stand correctly
- add this on the flip down of the tower part

-zip tie hooks for cables
increased slider hole height by 0.5mm for tolerance and closer fit

consider hard restricting slider when extending
- screw on stopper?

make slider 0.5mm thinner for sliding tolerance

add brim for easier hook printing
chamfer the air_tower magnet area to make it printable

fix slide colliding with top acrylic

make air tower nut holes deeper to accommodate m3x15

fixed ir led holes from 6/5/5/5/5/6 to 5.5
chamfer top_2 to make printable

magnet lock position seems wrong: slider_rail and deep slider -6mm: (89)
increase slider nut insert height 2.5->3
thin out air_2 except for nut area
increase cable channel height for easier passthrough

increase m3 hole for hinges to help threading
	4.9 dist : 3.1 dia

reduce depth of magnet mounts to make magnets more flush

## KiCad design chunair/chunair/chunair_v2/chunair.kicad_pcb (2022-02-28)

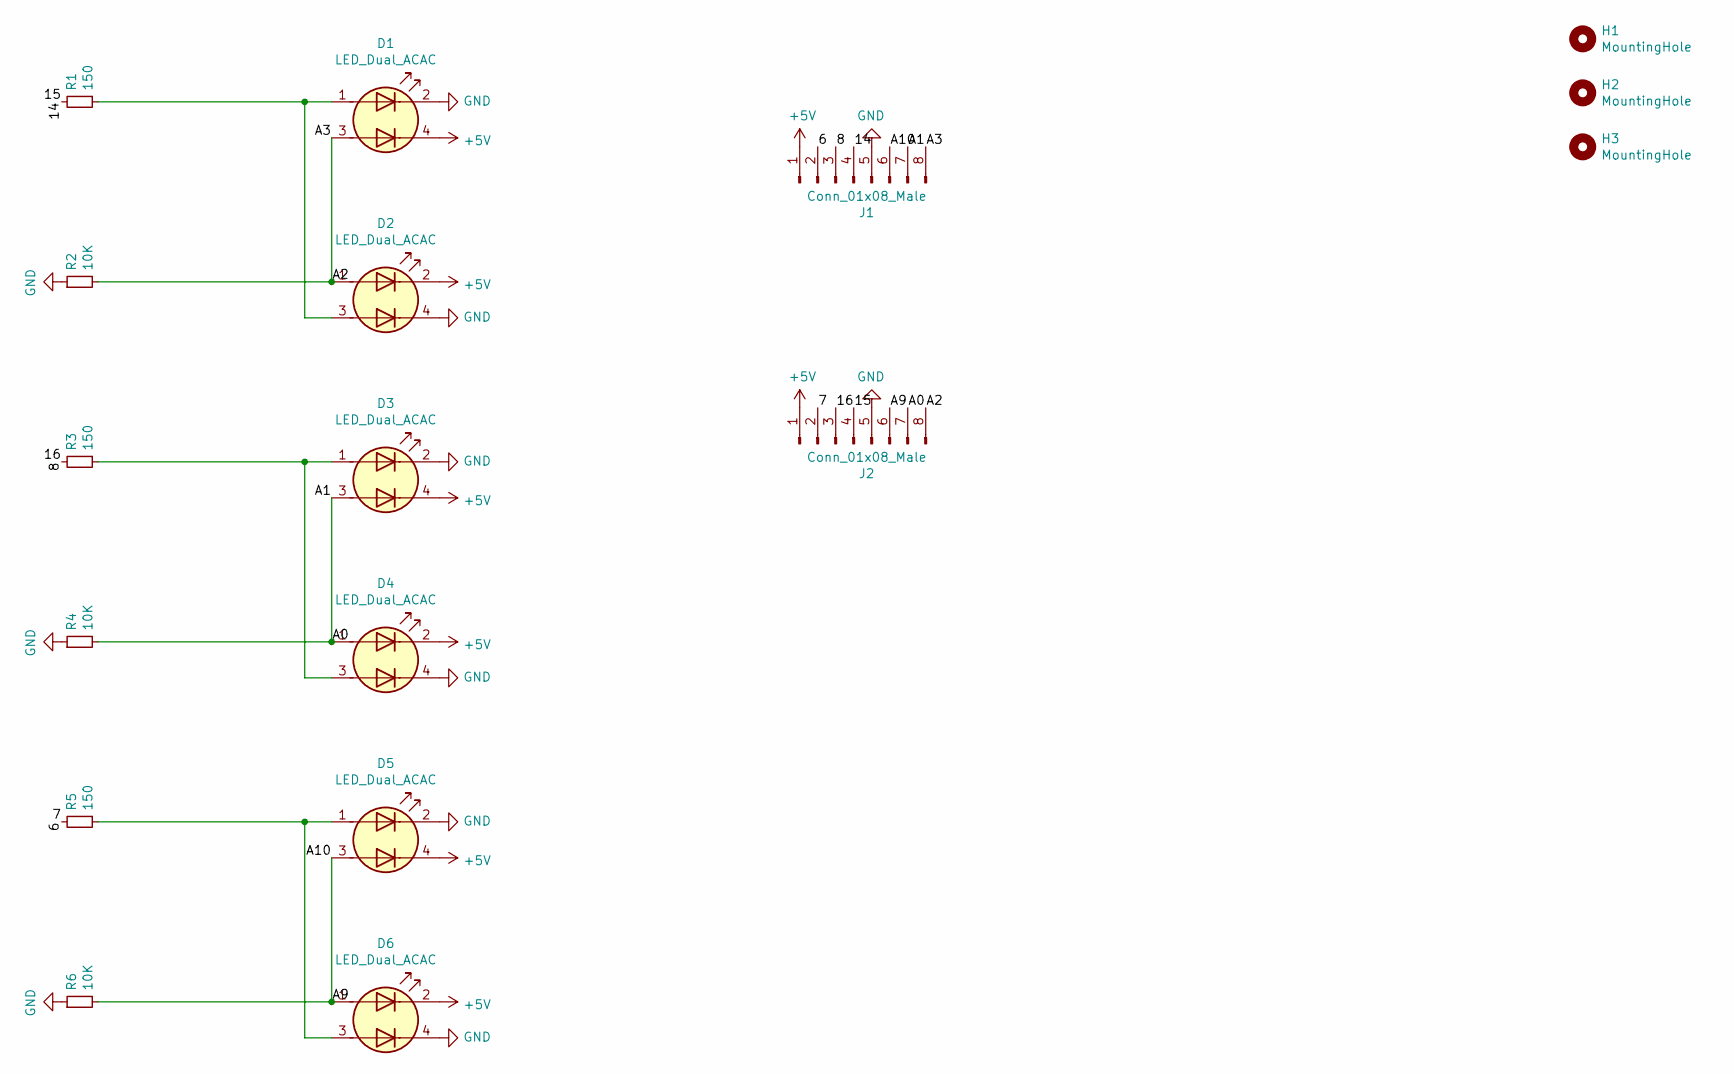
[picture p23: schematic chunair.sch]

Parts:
D1, D2, D3, D4, D5, D6: LED_Dual_ACAC; LED_D5.0mm_FlatTop
H1, H2, H3: MountingHole; MountingHole_3.2mm_M3
J1, J2: Conn_01x08_Male; SMD_8Pin
R1, R3, R5: 150; R_Axial_DIN0207_L6.3mm_D2.5mm_P7.62mm_Horizontal
R2, R4, R6: 10K; R_Axial_DIN0207_L6.3mm_D2.5mm_P7.62mm_Horizontal

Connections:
+5V: D1.4 (K2), D2.2 (K1), D3.4 (K2), D4.2 (K1), D5.4 (K2), D6.2 (K1), J1.1, J2.1
/6: J1.2, J2.2, R5.2
/14: J1.4, J2.4, R1.2
/16: J1.3, J2.3, R3.2
/A0: D3.3 (A2), D4.1 (A1), J1.7, J2.7, R4.2
/A2: D1.3 (A2), D2.1 (A1), J1.8, J2.8, R2.2
/A10: D5.3 (A2), D6.1 (A1), J1.6, J2.6, R6.2
GND: D1.2 (K1), D2.4 (K2), D3.2 (K1), D4.4 (K2), D5.2 (K1), D6.4 (K2), J1.5, J2.5, R2.1, R4.1, R6.1
unnamed: D1.1 (A1), D2.3 (A2), R1.1
unnamed: D3.1 (A1), D4.3 (A2), R3.1
unnamed: D5.1 (A1), D6.3 (A2), R5.1

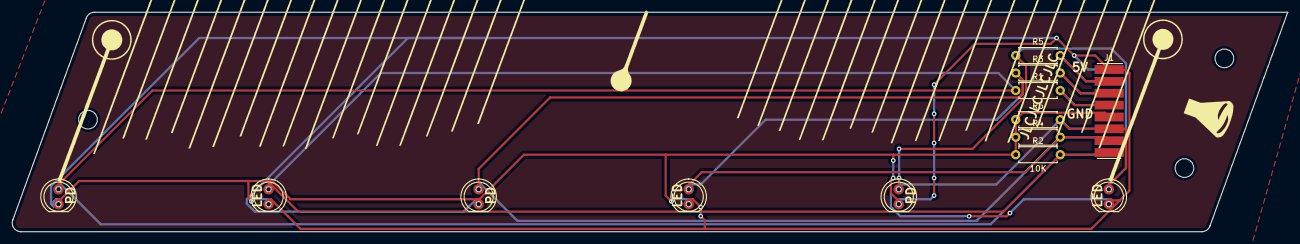
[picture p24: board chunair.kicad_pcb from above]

Board: 2 copper layers, 218.6 x 37.6 mm, 17 parts (1 on the bottom side), 11 nets.

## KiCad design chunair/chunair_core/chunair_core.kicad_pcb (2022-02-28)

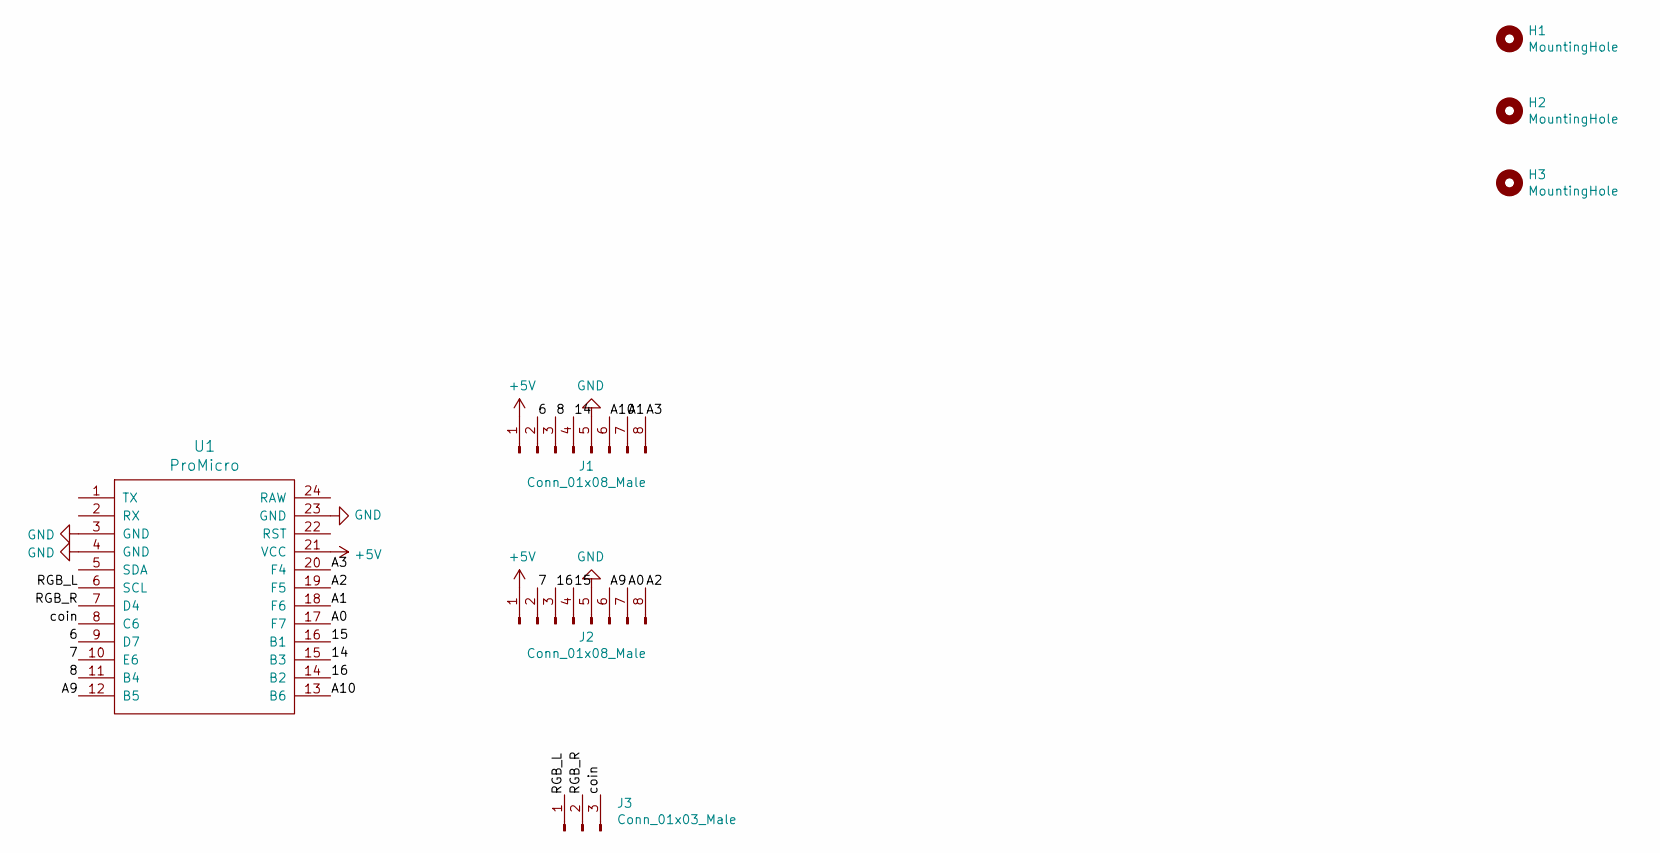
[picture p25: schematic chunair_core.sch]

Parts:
H1, H2, H3: MountingHole; MountingHole_3.2mm_M3
J1, J2: Conn_01x08_Male; SMD_8Pin
J3: Conn_01x03_Male; SMD_3Pin
U1: ProMicro; ProMicro-EnforcedTop

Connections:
+5V: J1.1, J2.1, U1.21 (VCC)
/6: J1.2, U1.9 (D7)
/7: J2.2, U1.10 (E6)
/8: J1.3, U1.11 (B4)
/14: J1.4, U1.15 (B3)
/15: J2.4, U1.16 (B1)
/16: J2.3, U1.14 (B2)
/A0: J2.7, U1.17 (F7)
/A1: J1.7, U1.18 (F6)
/A2: J2.8, U1.19 (F5)
/A3: J1.8, U1.20 (F4)
/A9: J2.6, U1.12 (B5)
/A10: J1.6, U1.13 (B6)
/RGB_L: J3.1, U1.6 (SCL)
/RGB_R: J3.2, U1.7 (D4)
/coin: J3.3, U1.8 (C6)
GND: J1.5, J2.5, U1.3 (GND), U1.4 (GND), U1.23 (GND)

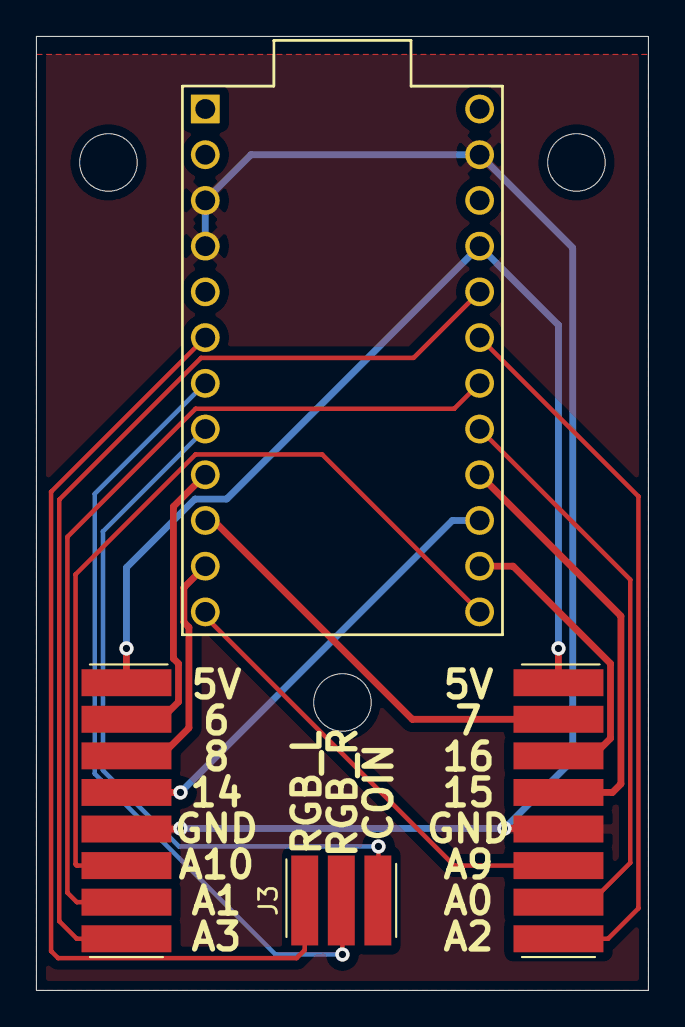
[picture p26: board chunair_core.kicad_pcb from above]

Board: 2 copper layers, 34.0 x 53.0 mm, 7 parts (0 on the bottom side), 17 nets.

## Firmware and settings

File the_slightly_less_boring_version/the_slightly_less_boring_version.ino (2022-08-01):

// Basic Chunithm Slider Companion (IR, RGB, Billboard)
// Based off @mon the_boring_version, written by @SpeedyPotato

#include <Keyboard.h>
#include <FastLED.h>

#define NUM_IR 6          // Number of IR Beams
#define IR_THRESHOLD 0.6  // % required to trigger
struct {
  uint8_t irPin;    // LED Pin
  uint8_t recPin;   // Photodiode Pin
  uint32_t val;     // Caliibrated Value
  char key;         // Output Keystroke
} beams[NUM_IR] = {
  6, A9, 0, '4',  // 1
  16, A1, 0, '7', // 4
  7, A10, 0, '5', // 2
  14, A2, 0, '8', // 5
  8, A0, 0, '6',  // 3
  15, A3, 0, '9', // 6
};
// Above LEDS are 1(lowest) to 6(highest) - they are out of order for optimal polling

#define COIN 5        // Coin Pin
#define COIN_KEY '3'  // Output Keystroke

#define LEFT_PIN      3
#define RIGHT_PIN     4
#define NUM_LEDS 3
#define LED_NUM_MAX 66

// side 0: 5*10 billboard and 3 air strings
#define BOARD0_LEDS (5*10 + 3)
// side 1: 6*10 billboard and 3 air strings
#define BOARD1_LEDS (6*10 + 3)
// side 2: slider, don't care
struct {
  uint8_t board;   // LED output the data is for (0-1: billboard, 2: slider)
  CRGB data[LED_NUM_MAX]; // Buffer for LEDs
} ledData;

size_t off;
bool escape;

#define CALIBRATION_CYCLES 10

/**
   IR Beam Calibration Procedure
*/
void beamCalibration() {
  for (int i = 0; i < CALIBRATION_CYCLES; i++) {
    for (int j = 0; j < NUM_IR; j++) {
      beams[j].val += readBeam(j);
    }
  }
  for (int i = 0; i < NUM_IR; i++) {
    beams[i].val /= CALIBRATION_CYCLES;
  }
}

/**
   Reads output from a single beam
*/
int readBeam(int beamIndex) {
  digitalWrite(beams[beamIndex].irPin, HIGH);
  delayMicroseconds(200); //300 seems the highest that's needed, can go lower maybe
  int result = analogRead(beams[beamIndex].recPin);
  Serial.print(String(result) + "\t");
  digitalWrite(beams[beamIndex].irPin, LOW);
  return result;
}

void setup() {
  // data from game
  Serial.begin(115200);
  Keyboard.begin();

  for (uint8_t i = 0; i < NUM_IR; i++) {
    pinMode(beams[i].recPin, INPUT);
    pinMode(beams[i].irPin, OUTPUT);
  }
  beamCalibration();

  pinMode(COIN, INPUT_PULLUP);

  // just steal the raw array values lol
  FastLED.addLeds<WS2812B, LEFT_PIN, RGB>(&ledData.data[50], NUM_LEDS).setCorrection( TypicalLEDStrip );
  FastLED.addLeds<WS2812B, RIGHT_PIN, RGB>(&ledData.data[60], NUM_LEDS).setCorrection( TypicalLEDStrip );
  // initialize to white
  fill_solid(&ledData.data[50], NUM_LEDS, CRGB::White);
  fill_solid(&ledData.data[60], NUM_LEDS, CRGB::White);
  FastLED.show();
}

void loop() {
  for (uint8_t i = 0; i < NUM_IR; i++) {
    if (readBeam(i) < (IR_THRESHOLD * beams[i].val)) {
      Keyboard.press(beams[i].key);
    } else {
      Keyboard.release(beams[i].key);
    }
  }
  Serial.println();

  if(digitalRead(COIN) == LOW) {
    Keyboard.press(COIN_KEY);
  } else {
    Keyboard.release(COIN_KEY);
  }

  while (Serial.available()) {
    uint8_t b = Serial.read();

    if (b == 0xE0) {
      if (off > 2) {
        size_t len = off - 1;
        if (ledData.board == 0 && len == 3 * BOARD0_LEDS) {
          FastLED[0].showLeds();
        } else if (ledData.board == 1 && len == 3 * BOARD1_LEDS) {
          FastLED[1].showLeds();
        }
      }
      escape = false;
      off = 0;
      continue;
    }

    if (b == 0xD0) {
      escape = true;
      continue;
    }

    if (escape) {
      escape = false;
      b += 1;
    }

    if (off < sizeof(ledData)) {
      ((uint8_t*)&ledData)[off++] = b;
    }
  }
}

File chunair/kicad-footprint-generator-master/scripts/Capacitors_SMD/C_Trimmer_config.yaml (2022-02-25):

# SMD trimmer capacitors STYLE A
base:
    family: STYLE-A
    description: 'trimmer capacitor SMD horizontal'
    keywords: ''
    device:
        body:
            colour: 'white body'
        frame:
            colour: 'metal grey pins'
        contacts:
            colour: 'metal grey pins'
        cover:
           colour: 'white body'
        rotor:
           colour: 'white body'
    3d_prefix: '${KICAD6_3DMODEL_DIR}/Capacitors_SMD.3dshapes'
variants:
    - series: TZR1
      manufacturer: Murata
      footprint:
          x_mm: 2.2
          pad:
              x_mm: 0.5
              y_mm: 0.5
      device:
          body:
              x_mm: 1.7
              y_mm: 1.4
          chamfer:
              sides: []
              size_mm: 0.0
          projection: 
              sides: ['top', 'bottom', 'right']
              offset_mm: 0.1
              x_side_mm: 0.9
              y_side_mm: 0.6
      keywords: 'Murata TZR1'
      datasheet: http://www.murata.com/~/media/webrenewal/support/library/catalog/products/capacitor/trimmer/t13e.ashx?la=en-gb
    - series: TZY2
      manufacturer: Murata
      footprint:
          x_mm: 4.0
          pad:
              x_mm: 0.8
              y_mm: 1.2
      device:
          body:
              x_mm: 3.0
              y_mm: 2.1
          chamfer:
              sides: []
              size_mm: 0.0
          projection: 
              sides: ['top', 'bottom', 'right']
              offset_mm: 0.2
              x_side_mm: 1.8              
              y_side_mm: 1.0
      keywords: 'Murata TZY2'
      datasheet: http://www.murata.com/~/media/webrenewal/support/library/catalog/products/capacitor/trimmer/t13e.ashx?la=en-gb
    - series: TZW4
      manufacturer: Murata
      footprint:
          x_mm: 7.0
          pad:
              x_mm: 1.3
              y_mm: 2.5
      device:
          body:
              x_mm: 5.2
              y_mm: 4.0
          chamfer:
              sides: []
              size_mm: 0.0
          projection: 
              sides: ['top', 'bottom']
              offset_mm: 0.1
              x_side_mm: 3.0
              y_side_mm: 0.0
      keywords: 'Murata TZW4'
      datasheet: http://www.murata.com/~/media/webrenewal/support/library/catalog/products/capacitor/trimmer/t13e.ashx?la=en-gb
    - series: JR
      manufacturer: Voltronics
      footprint:
          x_mm: 4.4
          pad:
              x_mm: 1.0
              y_mm: 1.8
      device:
          body:
              x_mm: 3.5
              y_mm: 3.1
          chamfer:
              sides: ['left']
              size_mm: 0.6
          projection: 
              sides: ['right']
              offset_mm: 0.4
              x_side_mm: 0.0
              y_side_mm: 1.6
      keywords: 'Voltronics JR'
      datasheet: http://www.knowlescapacitors.com/File%20Library/Voltronics/English/GlobalNavigation/Products/Trimmer%20Capacitors/CerChipTrimCap.pdf
    - series: JN
      manufacturer: Voltronics
      footprint:
          x_mm: 2.2
          pad:
              x_mm: 0.5
              y_mm: 0.5
      device:
          body:
              x_mm: 1.7
              y_mm: 1.4
          chamfer:
              sides: []
              size_mm: 0.0
          projection: 
              sides: ['top', 'bottom', 'right']
              offset_mm: 0.1
              x_side_mm: 0.9
              y_side_mm: 0.6
      keywords: 'Voltronics JN'
      datasheet: http://www.knowlescapacitors.com/File%20Library/Voltronics/English/GlobalNavigation/Products/Trimmer%20Capacitors/CerChipTrimCap.pdf
    - series: JV
      manufacturer: Voltronics
      footprint:
          x_mm: 4.0
          pad:
              x_mm: 0.8
              y_mm: 1.2
      device:
          body:
              x_mm: 3.0
              y_mm: 2.1
          chamfer:
              sides: []
              size_mm: 0.0
          projection: 
              sides: ['top', 'bottom', 'right']
              offset_mm: 0.2
              x_side_mm: 1.8              
              y_side_mm: 1.0
      keywords: 'Voltronics JV'
      datasheet: http://www.knowlescapacitors.com/File%20Library/Voltronics/English/GlobalNavigation/Products/Trimmer%20Capacitors/CerChipTrimCap.pdf
    - series: JQ
      manufacturer: Voltronics
      footprint:
          x_mm: 3.2
          pad:
              x_mm: 0.55
              y_mm: 1.0
      device:
          body:
              x_mm: 2.5
              y_mm: 1.8
          chamfer:
              sides: []
              size_mm: 0.0
          projection: 
              sides: ['top', 'bottom', 'right']
              offset_mm: 0.2
              x_side_mm: 1.5            
              y_side_mm: 1.0
      keywords: 'Voltronics JQ'
      datasheet: http://www.knowlescapacitors.com/File%20Library/Voltronics/English/GlobalNavigation/Products/Trimmer%20Capacitors/CerChipTrimCap.pdf
---
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

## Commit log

2022-02-10 wip, todo air_2
    [12x2mm_magnet.SLDPRT, 8884T21_Heavy Duty Unthreaded Bumpers.SLDPRT, ac_chuni.SLDASM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]
2022-02-23 v1.0 | Handwired Proto
    [91292A118_18-8 Stainless Steel Socket Head Screw.SLDPRT, 92125A103_18-8 Stainless Steel Hex Drive Flat Head Screw.SLDPRT, 94500A266_316 Stainless Steel Button 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]
2022-02-25 Added firmware and air pcb
    [JST-PH-SMT-SIDE_ENTRY.fcstd, JST-PH-SMT-TOP_ENTRY.fcstd, JST_ZE_top_entry_pad_size.fcstd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]
2022-02-26 Added basic core breakout pcb, minor firmware updates
    [chunair_core-B_Cu.gbr, chunair_core-B_Mask.gbr, chunair_core-B_Paste.gbr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]
2022-02-28 v2.0 | Added first ordered revision of PCBs
    [chunair-B_Cu.gbr, chunair-B_Mask.gbr, chunair-B_Paste.gbr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]
2022-03-22 v1.0 | Final version and docs, pictures later
    [12x2mm_magnet.SLDPRT, 8884T21_Heavy Duty Unthreaded Bumpers.SLDPRT, 91292A118_18-8 Stainless Steel Socket Head Screw.SLDPRT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]
2022-04-07 Added optional clips for air towers
    [clip.3MF, clip.SLDPRT]
